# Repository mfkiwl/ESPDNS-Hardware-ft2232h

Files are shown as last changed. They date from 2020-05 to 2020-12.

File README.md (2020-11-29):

# ESPDNS-Hardware

Open-source DNS filter, similar to Pi-Hole, based around the ESP32. 
Designed to be usable by people without the experience necessary to setup a Raspberry-pi.

This repository contains the KiCad projects for the full product and the programmer boards.  

Imgur

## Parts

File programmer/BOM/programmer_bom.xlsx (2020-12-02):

Component | Description | Part | References | Value | Footprint | Quantity Per PCB | Datasheet | Rating | LCSC Part Number | Digikey Part Number | Alternate Datasheet | LCSC Alternate
1 | Unpolarized capacitor | C | C1 C2 C5 C6 C7 C8 C9 | 0.1uF | C_0603_1608Metric | 7 | ~ | 10V | C14663 | ~ | ~ | ~
2 | Unpolarized capacitor | C | C3 | 1uF | C_0603_1608Metric | 1 | ~ | 10V | C15849 | ~ | ~ | ~
3 | Light emitting diode | LED | D1 | BLU | LED_0603_1608Metric | 1 | https://www.we-online.de/katalog/datasheet/150060BS75000.pdf | ~ | C72041 | 732-4966-1-ND | https://datasheet.lcsc.com/szlcsc/Everlight-Elec-19-217-BHC-ZL1M2RY-3T_C72041.pdf | 19-217/BHC-ZL1M2RY/3T
4 | Light emitting diode | LED | D2 | GRN | LED_0603_1608Metric | 1 | https://www.we-online.de/katalog/datasheet/150060GS75000.pdf | ~ | C72043 | 732-4971-1-ND | https://datasheet.lcsc.com/szlcsc/Everlight-Elec-19-217-GHC-YR1S2-3T_C72043.pdf | 19-217/GHC-YR1S2/3T
5 | USB Micro Type B connector | USB_B_Micro | J1 | 10118192-0001LF | AMPHENOL_10118192-0001LF | 1 | https://www.amphenol-icc.com/media/wysiwyg/files/drawing/10118192.pdf | ~ | ~ | 1175-1627-ND | ~ | ~
6 | Generic connector, double row, 02x05, odd/even pin numbering scheme (row 1 odd numbers, row 2 even numbers), script generated (kicad-library-utils/schlib/autogen/connector/) | Conn_02x05_Odd_Even | J2 | 3220-10-0100-00 | CNC_3220-10-0100-00 | 1 | http://www.cnctech.us/pdfs/3220-XX-0100-00_.pdf | ~ | ~ | 1175-1627-ND | ~ | ~
7 | N-MOSFET transistor, gate/source/drain | Q_NMOS_GSD | Q1 Q2 | 2N7002ET1G | SOT-23 | 2 | https://www.onsemi.com/pub/Collateral/2N7002E-D.PDF | ~ | C8545 | 2N7002ET1GOSCT-ND | https://datasheet.lcsc.com/szlcsc/Changjiang-Electronics-Tech-CJ-2N7002_C8545.pdf | 2N7002
8 | Resistor | R | R3 R4 | 470 | R_0603_1608Metric | 2 | ~ | 1/10W | C23179 | ~ | ~ | ~
9 | Resistor | R | R1 R2 | 12K | R_0603_1608Metric | 2 | ~ | ~ | C22790 | ~ | ~ | ~
10 | 1.8-3.3V SMD Ultra Miniature Crystal Clock Oscillator, Abracon | ASDMB-xxxMHz | U3 | ASDMB-12.000MHz | Oscillator_SMD_Abracon_ASDMB-4Pin_2.5x2.0mm | 1 | https://abracon.com/Oscillators/ASDMB.pdf | ~ | C90619 | 535-11180-1-ND | https://datasheet.lcsc.com/szlcsc/Yangxing-Tech-O252012MEDH4MI_C90619.pdf | O252012MEDH4MI
11 | Hi Speed Double Channel USB UART/FIFO, LQFP-64 | FT2232HL | U2 | FT2232HL | LQFP-64_10x10mm_P0.5mm | 1 | https://www.ftdichip.com/Support/Documents/DataSheets/ICs/DS_FT2232H.pdf | ~ | C27882 | 768-1347-ND | ~ | ~
12 | 500mA Low Dropout Voltage Regulator, Fixed Output 3.3V, SOT-23-5 | TLV75533PDBV | U1 | TLV75533PDBV | SOT-23-5 | 1 | http://www.ti.com/lit/ds/symlink/tlv755p.pdf | ~ | C404027 | 296-50411-1-ND | ~ | ~
Component Groups: | 12
Component Count: | 21
Fitted Components: | 21
Number of PCBs: | 1
Total components: | 21
Schematic Version:
Schematic Date:
PCB Variant: | default
BoM Date: | 2020-12-02 09:36
Schematic Source: | programmer.sch
KiCad Version: | Eeschema (5.1.7)-1

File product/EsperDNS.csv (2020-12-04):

Comment | Designator | Footprint | LCSC
1uF | C1,C4,C9 | Capacitor_SMD:C_0402_1005Metric | C52923
0.1uF | C2,C5,C6,C7,C8,C11 | Capacitor_SMD:C_0402_1005Metric | C1525
10uF | C3,C10 | Capacitor_SMD:C_0805_2012Metric | C15850
GRN | D1 | Diode_SMD:D_0603_1608Metric | C72043
RS-3535MWAR | D2 | LED_SMD:LED_RGB_PLCC-6 | C110402
Ferrite_Bead | FB1,FB2 | Inductor_SMD:L_0805_2012Metric | C1015
MountingHole | H1,H2 | MountingHole:MountingHole_2.2mm_M2_Pad
10118192-0001LF | J1 | Esper_Footprints:AMPHENOL_10118192-0001LF
Conn_02x05_Odd_Even | J2 | Esper_Footprints:CNC_3220-10-0100-00
RJ45_Amphenol_RJMG1BD3B8K1ANR | J3 | Connector_RJ:RJ45_Amphenol_RJMG1BD3B8K1ANR
2N7002 | Q1,Q2,Q3 | Package_TO_SOT_SMD:SOT-23 | C8545
470 | R1 | Resistor_SMD:R_0402_1005Metric | C270656
270 | R17,R21 | Resistor_SMD:R_0603_1608Metric | C22966
10K | R2,R8,R10,R11,R12,R24 | Resistor_SMD:R_0402_1005Metric | C25744
12.1K | R23 | Resistor_SMD:R_0402_1005Metric | C25852
47 | R3,R4 | Resistor_SMD:R_0603_1608Metric | C23182
82 | R5 | Resistor_SMD:R_1206_3216Metric | C247183
49.9 | R6,R7,R9,R13,R14,R15,R16,R18,R19,R20,R22 | Resistor_SMD:R_0402_1005Metric | C25120
PTS645VH83-2 LFS | SW1 | Button_Switch_THT:SW_Tactile_SPST_Angled_PTS645Vx83-2LFS
AZ1117EH-3.3TRG1 | U1 | Package_TO_SOT_SMD:SOT-223 | C108494
ESP32-WROOM-32E | U2 | RF_Module:ESP32-WROOM-32 | C52923
LAN8720A | U3 | Package_DFN_QFN:QFN-24-1EP_4x4mm_P0.5mm_EP2.6x2.6mm_ThermalVias | C45223

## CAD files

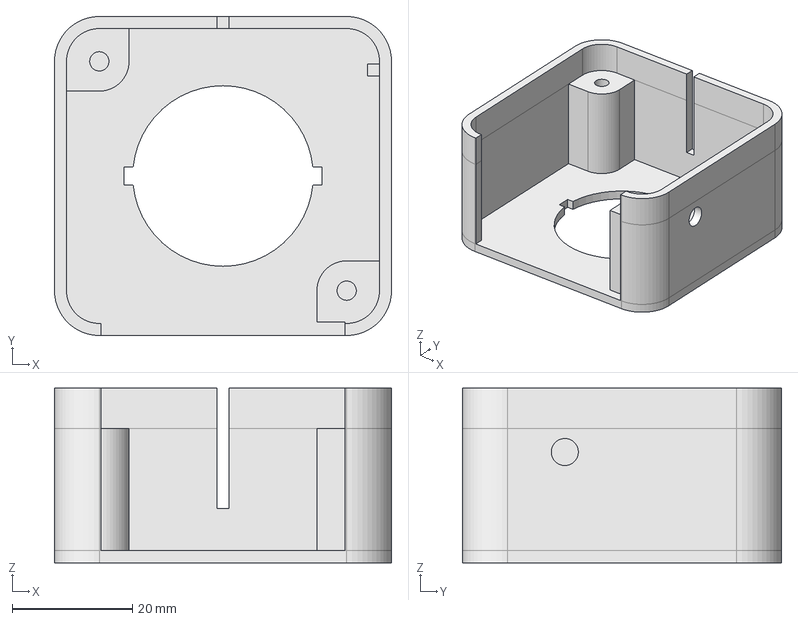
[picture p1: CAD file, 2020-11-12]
Enclosure/Enclosure.FCStd
56.0 x 53.0 x 29.0 mm

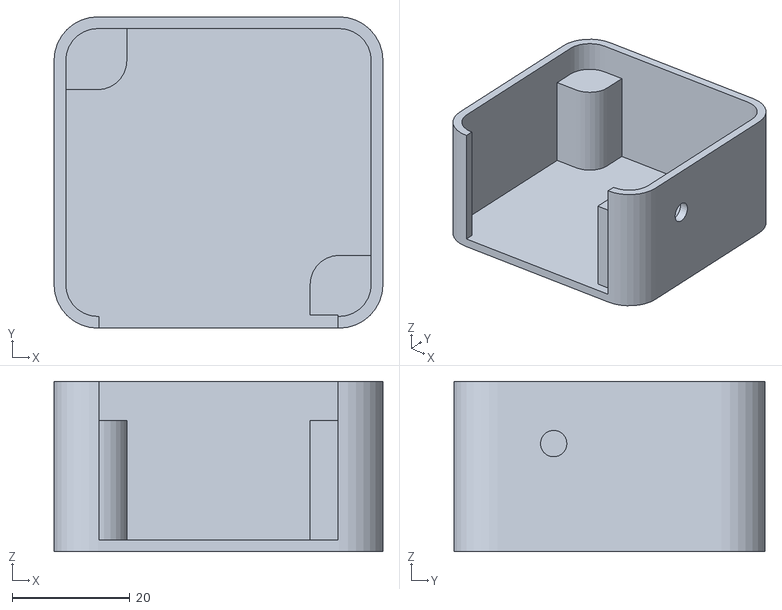
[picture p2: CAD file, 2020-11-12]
Enclosure/EnclosureTop.stl
56.0 x 53.0 x 29.0

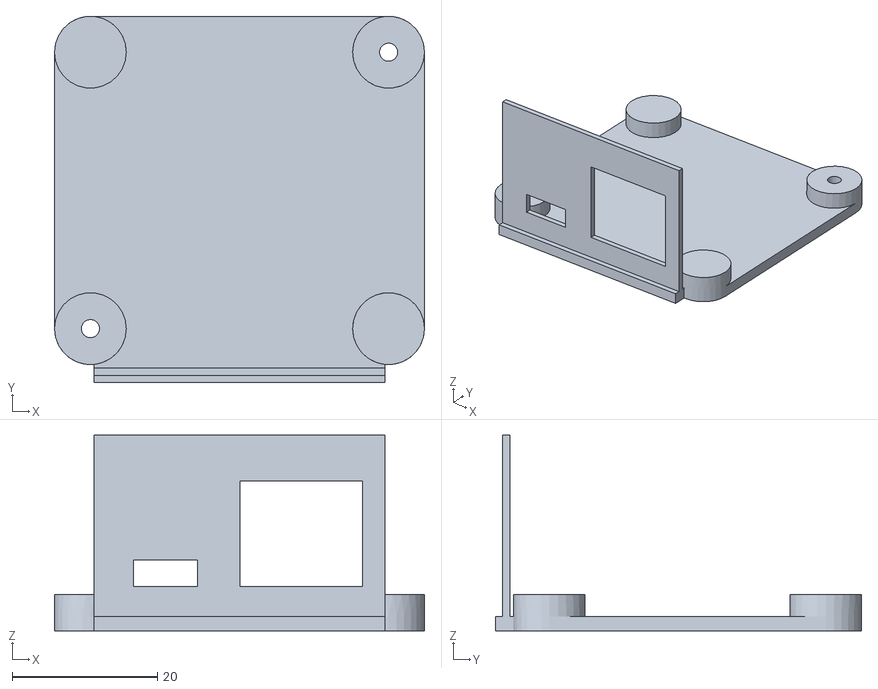
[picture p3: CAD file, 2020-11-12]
Enclosure/EnclosureBottom.stl
51.0 x 50.5 x 27.0

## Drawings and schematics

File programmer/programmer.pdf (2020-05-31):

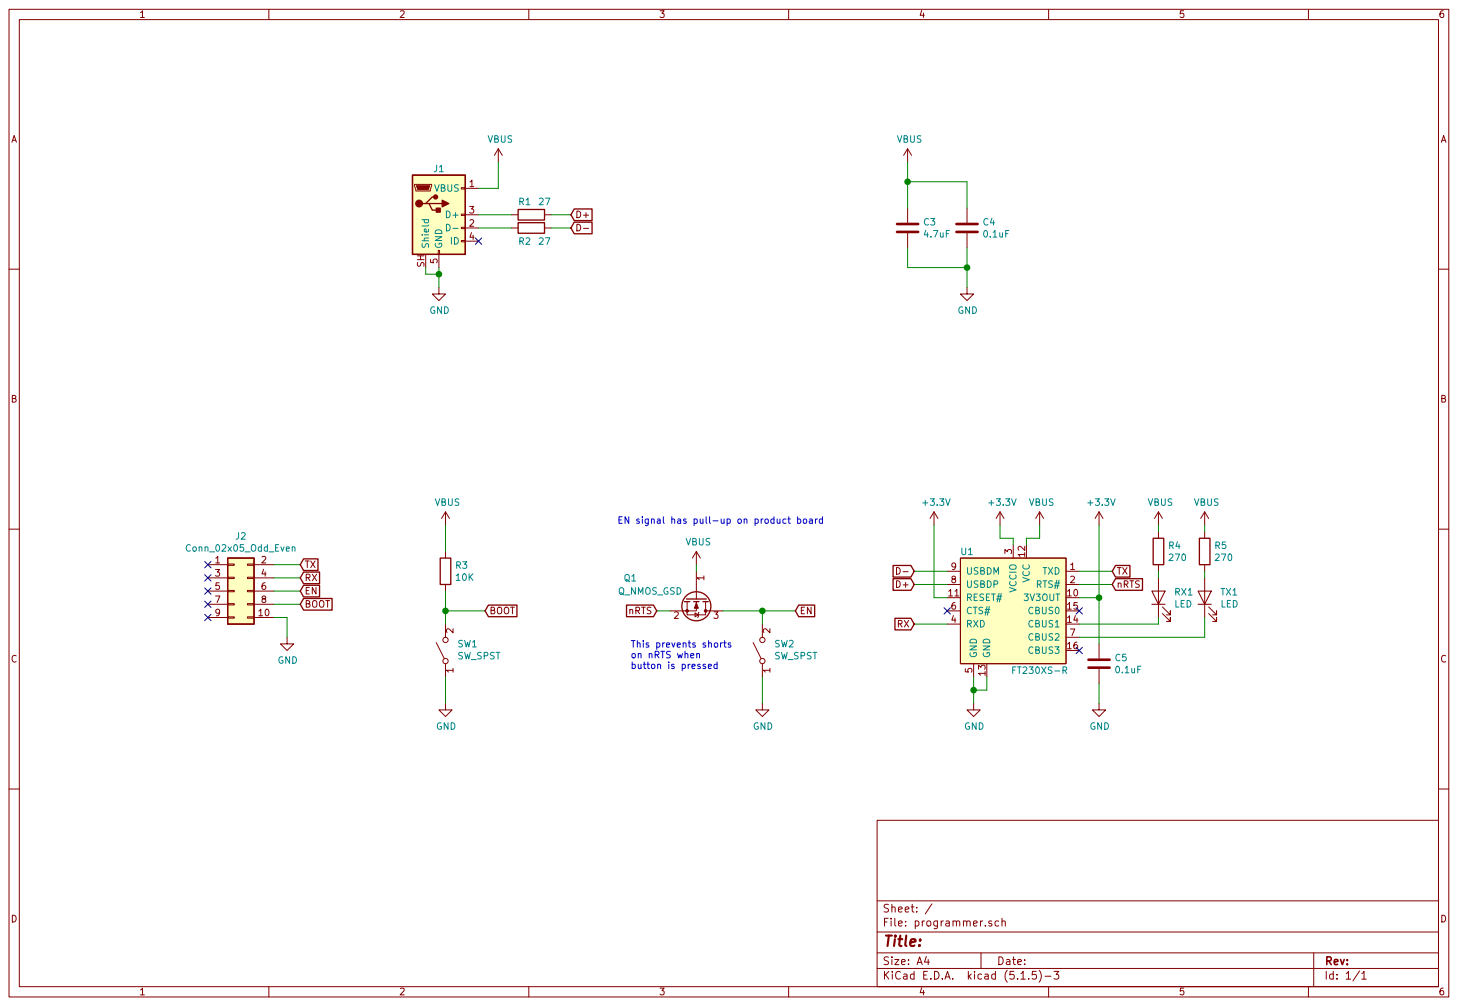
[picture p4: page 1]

EN signal has pull-up on product board

This prevents shorts on nRTS when

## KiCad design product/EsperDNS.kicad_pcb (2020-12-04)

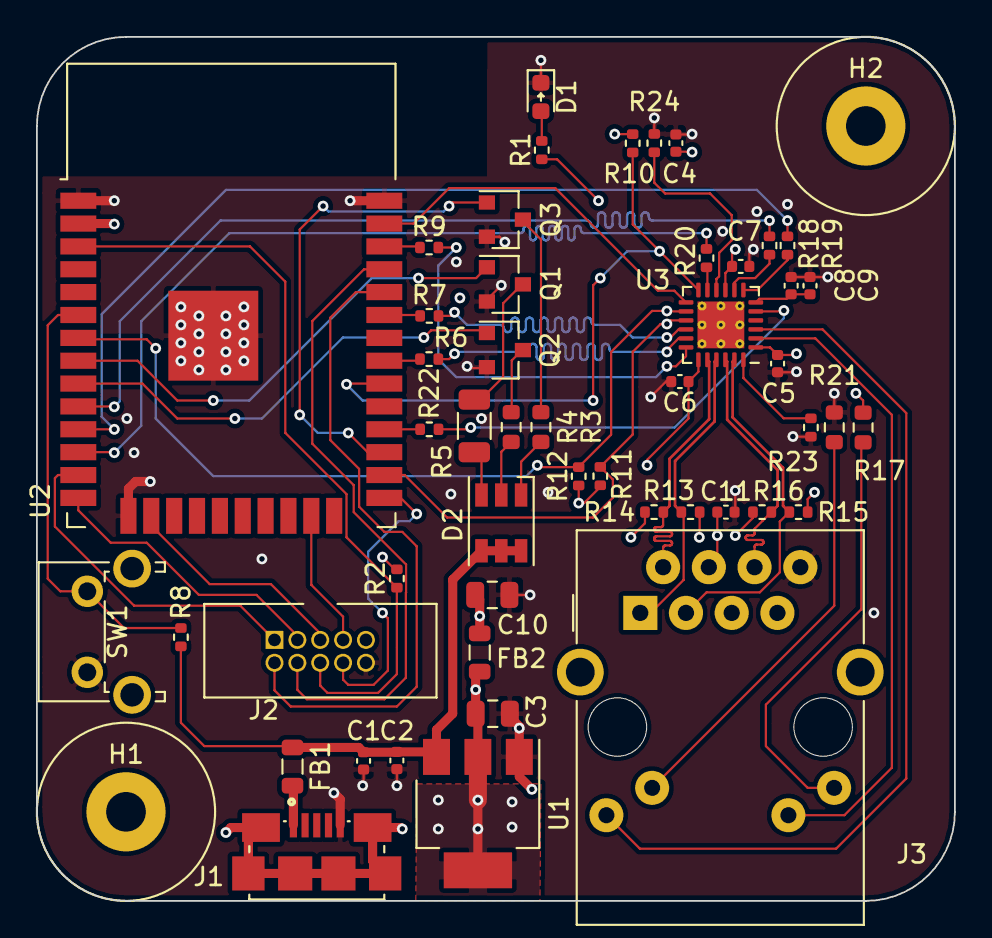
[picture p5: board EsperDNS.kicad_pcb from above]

Board: 4 copper layers, 51.0 x 48.0 mm, 51 parts (0 on the bottom side), 54 nets.

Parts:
C1, C4, C9: 1uF; C_0402_1005Metric
C2, C5, C6, C7, C8, C11: 0.1uF; C_0402_1005Metric
C3, C10: 10uF; C_0805_2012Metric
D1: GRN; D_0603_1608Metric
D2: RS-3535MWAR; LED_RGB_PLCC-6
FB1, FB2: Ferrite_Bead; L_0805_2012Metric
H1, H2: MountingHole; MountingHole_2.2mm_M2_Pad
J1: 10118192-0001LF; AMPHENOL_10118192-0001LF
J2: Conn_02x05_Odd_Even; CNC_3220-10-0100-00
J3: RJ45_Amphenol_RJMG1BD3B8K1ANR
Q1, Q2, Q3: 2N7002; SOT-23
R1: 470; R_0402_1005Metric
R2, R8, R10, R11, R12, R24: 10K; R_0402_1005Metric
R3, R4: 47; R_0603_1608Metric
R5: 82; R_1206_3216Metric
R6, R7, R9, R13, R14, R15, R16, R18, R19, R20, R22: 49.9; R_0402_1005Metric
R17, R21: 270; R_0603_1608Metric
R23: 12.1K; R_0402_1005Metric
SW1: PTS645VH83-2 LFS; SW_Tactile_SPST_Angled_PTS645Vx83-2LFS
U1: AZ1117EH-3.3TRG1; SOT-223
U2: ESP32-WROOM-32E; ESP32-WROOM-32
U3: LAN8720A; QFN-24-1EP_4x4mm_P0.5mm_EP2.6x2.6mm_ThermalVias

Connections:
+3.3VA: C4.1, C5.1, C6.1, C10.1, C11.1, FB2.1, J3.R4, J3.R5, R10.1, R11.1, R12.1, R13.1, R14.1, R15.1, R16.1, R17.1, U3.1, U3.19
+3V3: C3.1, C7.1, FB2.2, R1.1, R2.2, U1.2, U1.4, U2.2, U3.9
/ESP32/CLK_R: R22.2, U2.28
/ESP32/TXD0_R: R6.1, U2.31
/ESP32/TXD1_R: R9.1, U2.36
/ESP32/TXEN_R: R7.1, U2.33
/Ethernet/CRS_DV_R: R20.1, U3.11
/Ethernet/LEDG_K: J3.L3, R21.1
/Ethernet/LEDY_A: J3.L1, R17.2
/Ethernet/PHYAD0: R24.1, U3.10
/Ethernet/RBIAS: R23.1, U3.24
/Ethernet/RD+: J3.R3, R15.2, U3.23
/Ethernet/RD-: J3.R6, R16.2, U3.22
/Ethernet/RX0_R: R18.1, U3.8
/Ethernet/RX1_R: R19.1, U3.7
/Ethernet/TD+: J3.R1, R13.2, U3.21
/Ethernet/TD-: J3.R2, R14.2, U3.20
Block: R8.2, SW1.2, U2.6
Blue: Q3.1, U2.27
CLK50MHZ: R22.1, U3.5
CRS_DV: R20.2, U2.12
EN: J2.6, R2.1, U2.3
Earth: H1.1, H2.1, J1.6, J3.13
GND: C1.2, C2.2, C3.2, C4.2, C5.2, C6.2, C7.2, C8.2, C9.2, C10.2, C11.2, D1.1, J1.5, J2.10, J3.R8, Q1.2, Q2.2, Q3.2, R21.2, R23.2, R24.2, SW1.1, U1.1, U2.1, U2.15, U2.38, U2.39, U3.25
Green: Q2.1, U2.9
IO0: J2.8, U2.25
LED1_REGOFF: J3.L4, U3.3
LED2_nINTSEL: J3.L2, U3.2
MDC: U2.37, U3.13
MDIO: R10.2, U2.30, U3.12
MTCK: J2.5, U2.16
MTDI: J2.3, U2.14
MTDO: J2.7, U2.23
MTMS: J2.1, U2.13
unnamed: D1.2, R1.2
unnamed: D2.1, R3.1
unnamed: D2.2, R4.1
unnamed: D2.3, R5.1
unnamed: FB1.2, J1.1
unnamed: Q1.3, R5.2
unnamed: Q2.3, R4.2
unnamed: Q3.3, R3.2
RX: J2.4, U2.35
RXD0: R18.2, U2.10
RXD1: R19.2, U2.11
Red: Q1.1, U2.8
TX: J2.2, U2.34
TXD0: R6.2, U3.17
TXD1: R9.2, U3.18
TXEN: R7.2, U3.16
VBUS: C1.1, C2.1, D2.4, D2.5, D2.6, FB1.1, R8.1, U1.3
VDDCR: C8.1, C9.1, U3.6
nINT: R12.2, U2.7, U3.14
nRST: R11.2, U2.26, U3.15

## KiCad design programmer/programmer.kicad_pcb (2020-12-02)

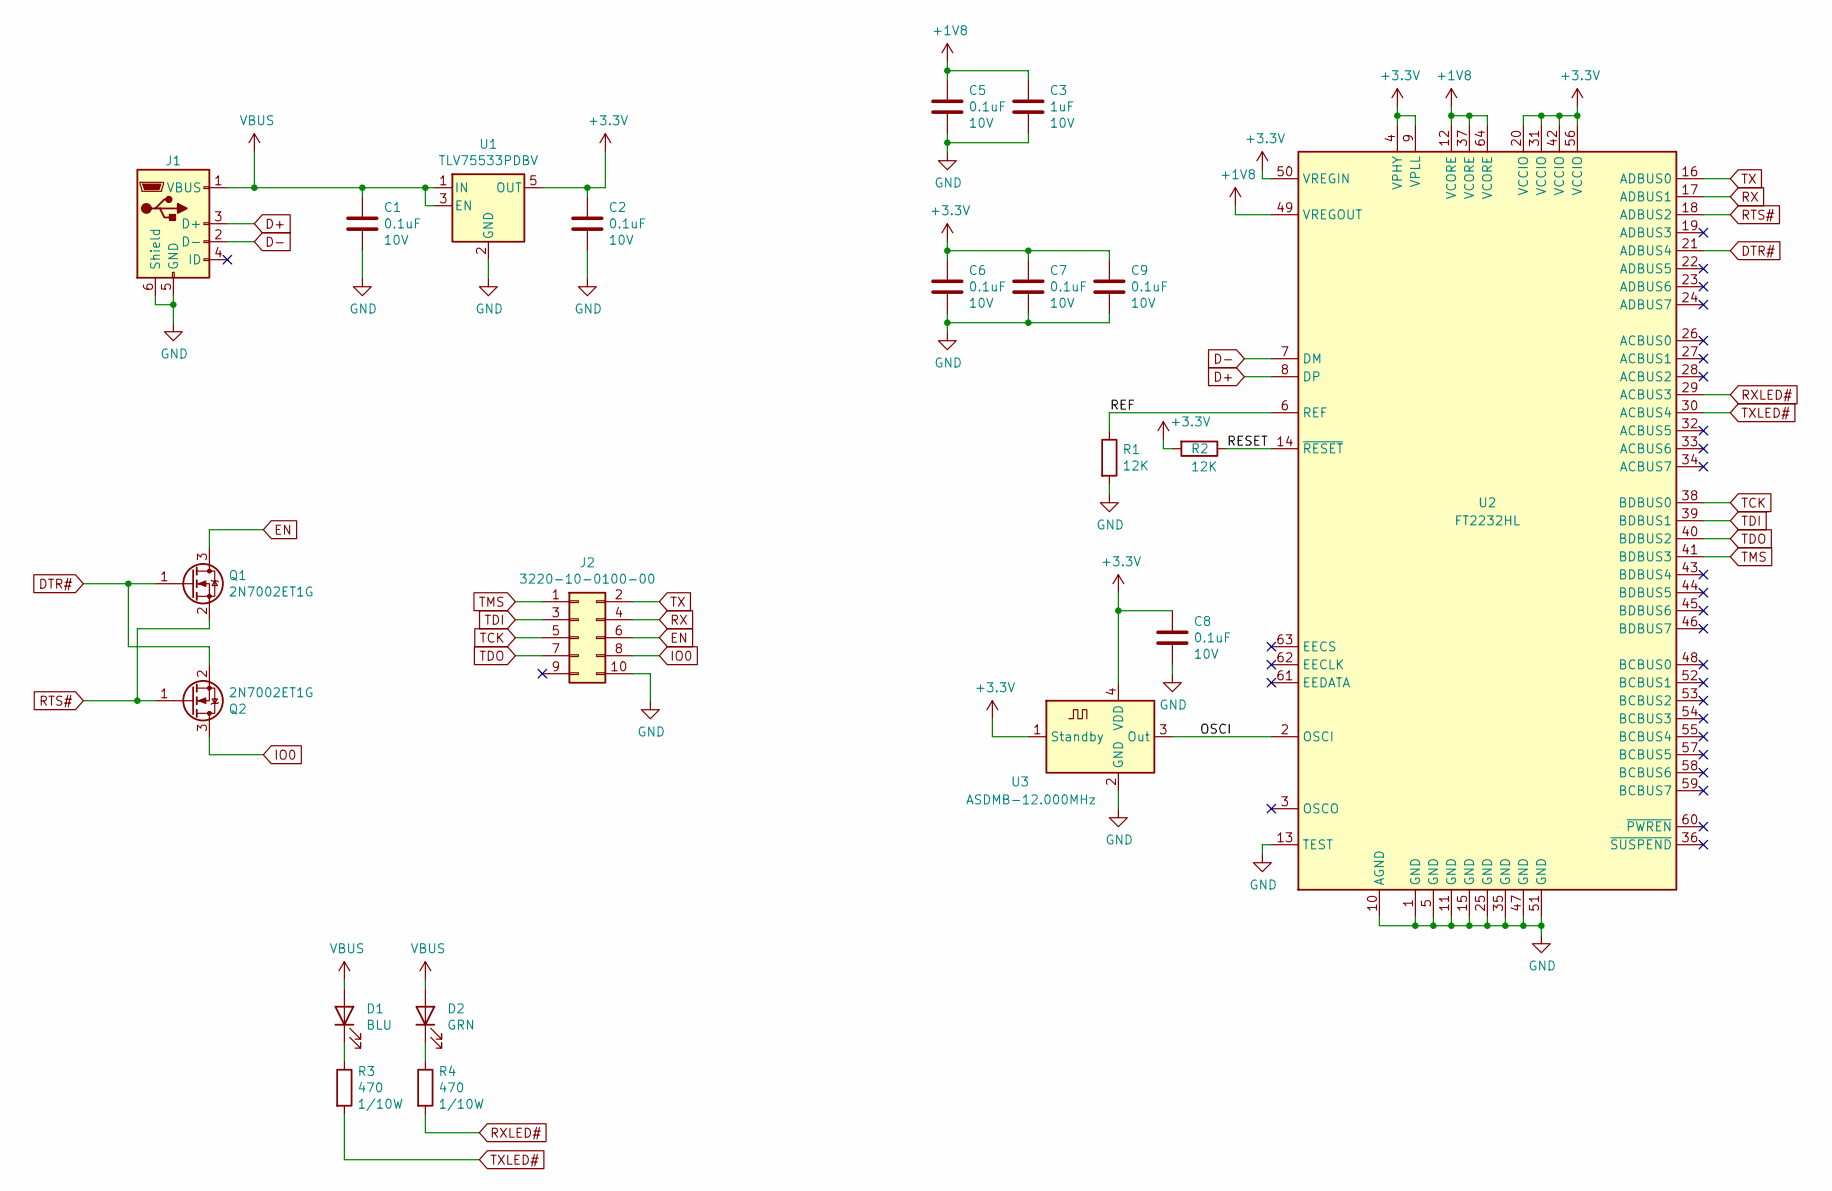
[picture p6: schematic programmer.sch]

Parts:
C1, C2, C5, C6, C7, C8, C9: 0.1uF; C_0603_1608Metric; Rating 10V; LCSC Part Number C14663
C3: 1uF; C_0603_1608Metric; Rating 10V; LCSC Part Number C15849
D1: BLU; LED_0603_1608Metric; Digikey Part Number 732-4966-1-ND
D2: GRN; LED_0603_1608Metric; Digikey Part Number 732-4971-1-ND
J1: 10118192-0001LF; AMPHENOL_10118192-0001LF; Digikey Part Number 1175-1627-ND
J2: 3220-10-0100-00; CNC_3220-10-0100-00; Digikey Part Number 1175-1627-ND
Q1, Q2: 2N7002ET1G; SOT-23; Digikey Part Number 2N7002ET1GOSCT-ND
R1, R2: 12K; R_0603_1608Metric; LCSC Part Number C22790
R3, R4: 470; R_0603_1608Metric; Rating 1/10W; LCSC Part Number C23179
U1: TLV75533PDBV; SOT-23-5; Digikey Part Number 296-50411-1-ND
U2: FT2232HL; LQFP-64_10x10mm_P0.5mm; Digikey Part Number 768-1347-ND
U3: ASDMB-12.000MHz; Oscillator_SMD_Abracon_ASDMB-4Pin_2.5x2.0mm; Digikey Part Number 535-11180-1-ND

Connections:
+1V8: C3.1, C5.1, U2.12 (VCORE), U2.37 (VCORE), U2.49 (VREGOUT), U2.64 (VCORE)
+3V3: C2.1, C6.1, C7.1, C8.1, C9.1, R2.2, U1.5 (OUT), U2.4 (VPHY), U2.9 (VPLL), U2.20 (VCCIO), U2.31 (VCCIO), U2.42 (VCCIO), U2.50 (VREGIN), U2.56 (VCCIO), U3.1 (Standby), U3.4 (VDD)
/OSCI: U2.2 (OSCI), U3.3 (Out)
/REF: R1.1, U2.6 (REF)
/RESET: R2.1, U2.14 (~RESET)
D+: J1.3 (D+), U2.8 (DP)
D-: J1.2 (D-), U2.7 (DM)
DTR#: Q1.1 (G), Q2.2 (S), U2.21 (ADBUS4)
EN: J2.6, Q1.3 (D)
GND: C1.2, C2.2, C3.2, C5.2, C6.2, C7.2, C8.2, C9.2, J1.5 (GND), J1.6 (Shield), J2.10, R1.2, U1.2 (GND), U2.1 (GND), U2.5 (GND), U2.10 (AGND), U2.11 (GND), U2.13 (TEST), U2.15 (GND), U2.25 (GND), U2.35 (GND), U2.47 (GND), U2.51 (GND), U3.2 (GND)
IO0: J2.8, Q2.3 (D)
unnamed: D1.1 (K), R3.1
unnamed: D2.1 (K), R4.1
RTS#: Q1.2 (S), Q2.1 (G), U2.18 (ADBUS2)
RX: J2.4, U2.17 (ADBUS1)
RXLED#: R4.2, U2.29 (ACBUS3)
TCK: J2.5, U2.38 (BDBUS0)
TDI: J2.3, U2.39 (BDBUS1)
TDO: J2.7, U2.40 (BDBUS2)
TMS: J2.1, U2.41 (BDBUS3)
TX: J2.2, U2.16 (ADBUS0)
TXLED#: R3.2, U2.30 (ACBUS4)
VBUS: C1.1, D1.2 (A), D2.2 (A), J1.1 (VBUS), U1.1 (IN), U1.3 (EN)

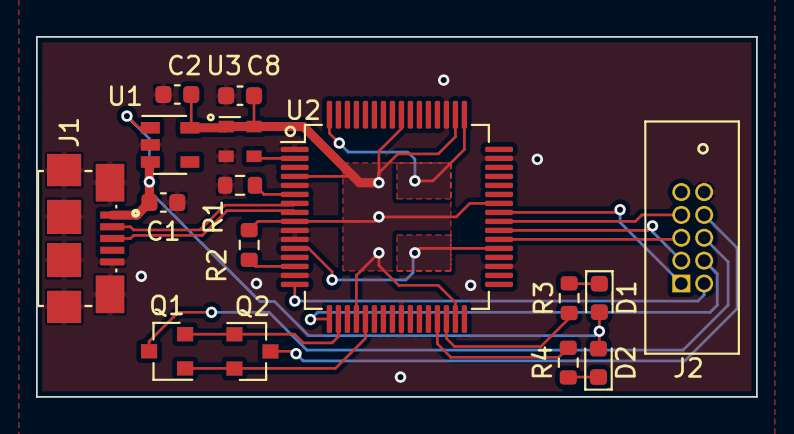
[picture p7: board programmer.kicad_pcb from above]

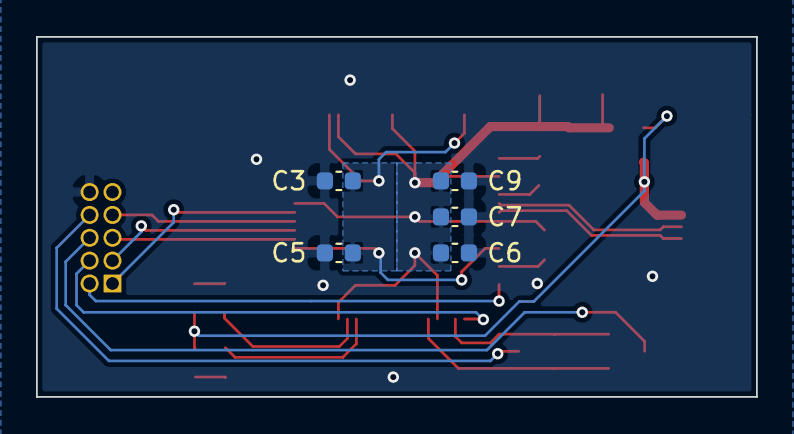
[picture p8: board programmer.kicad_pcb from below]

Board: 2 copper layers, 40.0 x 20.0 mm, 21 parts (5 on the bottom side), 23 nets.

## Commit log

2019-12-05 First page added
    [EsperDNS.kicad_pcb, EsperDNS.sch]
2019-12-05 Second page finished
    [EsperDNS.sch, Page 1.sch, Page 2.sch]
2019-12-05 Corrected mistakes, added refdes
    [Page 1.sch, Page 2.sch]
2019-12-06 Started assigning footprints
    [Page 1.sch, Page 2.sch]
2019-12-06 Assigning footprints
    [EsperDNS.sch, Page 1.sch, Page 2.sch]
2019-12-06 Started laying out board
    [EsperDNS.sch, Page 1.sch, Page 2.sch]
2019-12-06 Schematic changes
    [Page 1.sch]
2019-12-09 Worked on board
    [EsperDNS.kicad_pcb, Page 2.sch]
2019-12-10 Finished first revision of board
    [EsperDNS.kicad_pcb]
2019-12-11 Started on programmer board
    [EsperDNS.kicad_pcb, EsperDNS.sch, Page 1.sch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]
2019-12-11 Added first revision of programmer board
    [EsperDNS.kicad_pcb, Page 2.sch, programmer.kicad_pcb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]
2019-12-14 Changed programmer parts to LCSC parts, added part numbers
    [EsperDNS-B_Cu.gbr, EsperDNS-B_Mask.gbr, EsperDNS-B_Paste.gbr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]
2019-12-15 Added LCSC part numbers for product board
    [EsperDNS.kicad_pcb, EsperDNS.sch, Page 1.sch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]
2019-12-15 Added .gitignore and added BOMs for programmer
    [EsperDNS-B_Cu.gbr, EsperDNS-B_Mask.gbr, EsperDNS-B_Paste.gbr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]
2020-05-16 Swapped TX & RX on Product Board
    [EsperDNS.kicad_pcb, Page 1.sch, Page 2.sch]
2020-05-31 Moved connector and added silkscreen labels on product board
    [EsperDNS.kicad_pcb, programmer.kicad_pcb]
2020-06-18 Last commit before removing oscillator, currently boots and obtains IP address
2020-08-12 Removed oscillator, replaced with IO17
    [EsperDNS.kicad_pcb, Page 1.sch, Page 2.sch]
2020-08-14 First Draft Of New Form Factor
    [EsperDNS-B_Cu.gbr, EsperDNS-B_Mask.gbr, EsperDNS-B_Paste.gbr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]
2020-08-27 Editted traces to improve signal intregrity
    [EsperDNS.kicad_pcb, EsperDNS.sch, Page 1.sch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]
2020-08-28 Started adding LEDs and pushbuttons to board
    [EsperDNS.kicad_pcb, Page 2.sch]
2020-09-01 Added block button and RGB LED
    [EsperDNS.kicad_pcb, Page 2.sch]
2020-09-14 Added buttons and LEDs
    [BOM.csv, BOM.xlsx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]
2020-11-12 Changed board outline and mounting to better fit inside enclosure
    [BOM.csv, BOM.xlsx, Bom_8363950.xlsx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]
2020-12-02 Updated programmer to include jtag and dtr signals. Swapped FT230X for FT2232HL
    [programmer.kicad_pcb, programmer.sch]
2020-12-02 Finished version 2 of programmer, now with JTAG
    [Programmer BOM DigiKey.xlsx, Programmer BOM JLCPCB.xlsx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]
2020-12-04 Finished layout
    [BOM.xlsx, Bom_8363950.xlsx, Digikey BOM.xlsx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]
2020-12-04 Added LCSC part numbers, and tweaked a few part footprints
    [BOM.xlsx, Bom_8363950.xlsx, Digikey BOM.xlsx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]
